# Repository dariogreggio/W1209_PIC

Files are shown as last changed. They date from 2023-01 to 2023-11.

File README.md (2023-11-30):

# W1209_PIC
a W1209 thermostat clone, made with a PIC, with added USB and OLED

NEW FEATURES: a complete game machine :)

and a fully configurable Timer
1) up to 999 seconds
2) selectable seconds or tenths of seconds (more customizable if needed)
3) start and stop by means of buttons, and external connector
4) stop/reset can be disabled
5) can start automatically at power-on
6) output can be either on or off (reversed mode) during timer operations
7) external input can work as either start or stop
8) complete real-time-clock (date and time) available
9) external output can be used as an analog input to change timing (customized)
12V (5..24V max) operating power supply

and a voltmeter!

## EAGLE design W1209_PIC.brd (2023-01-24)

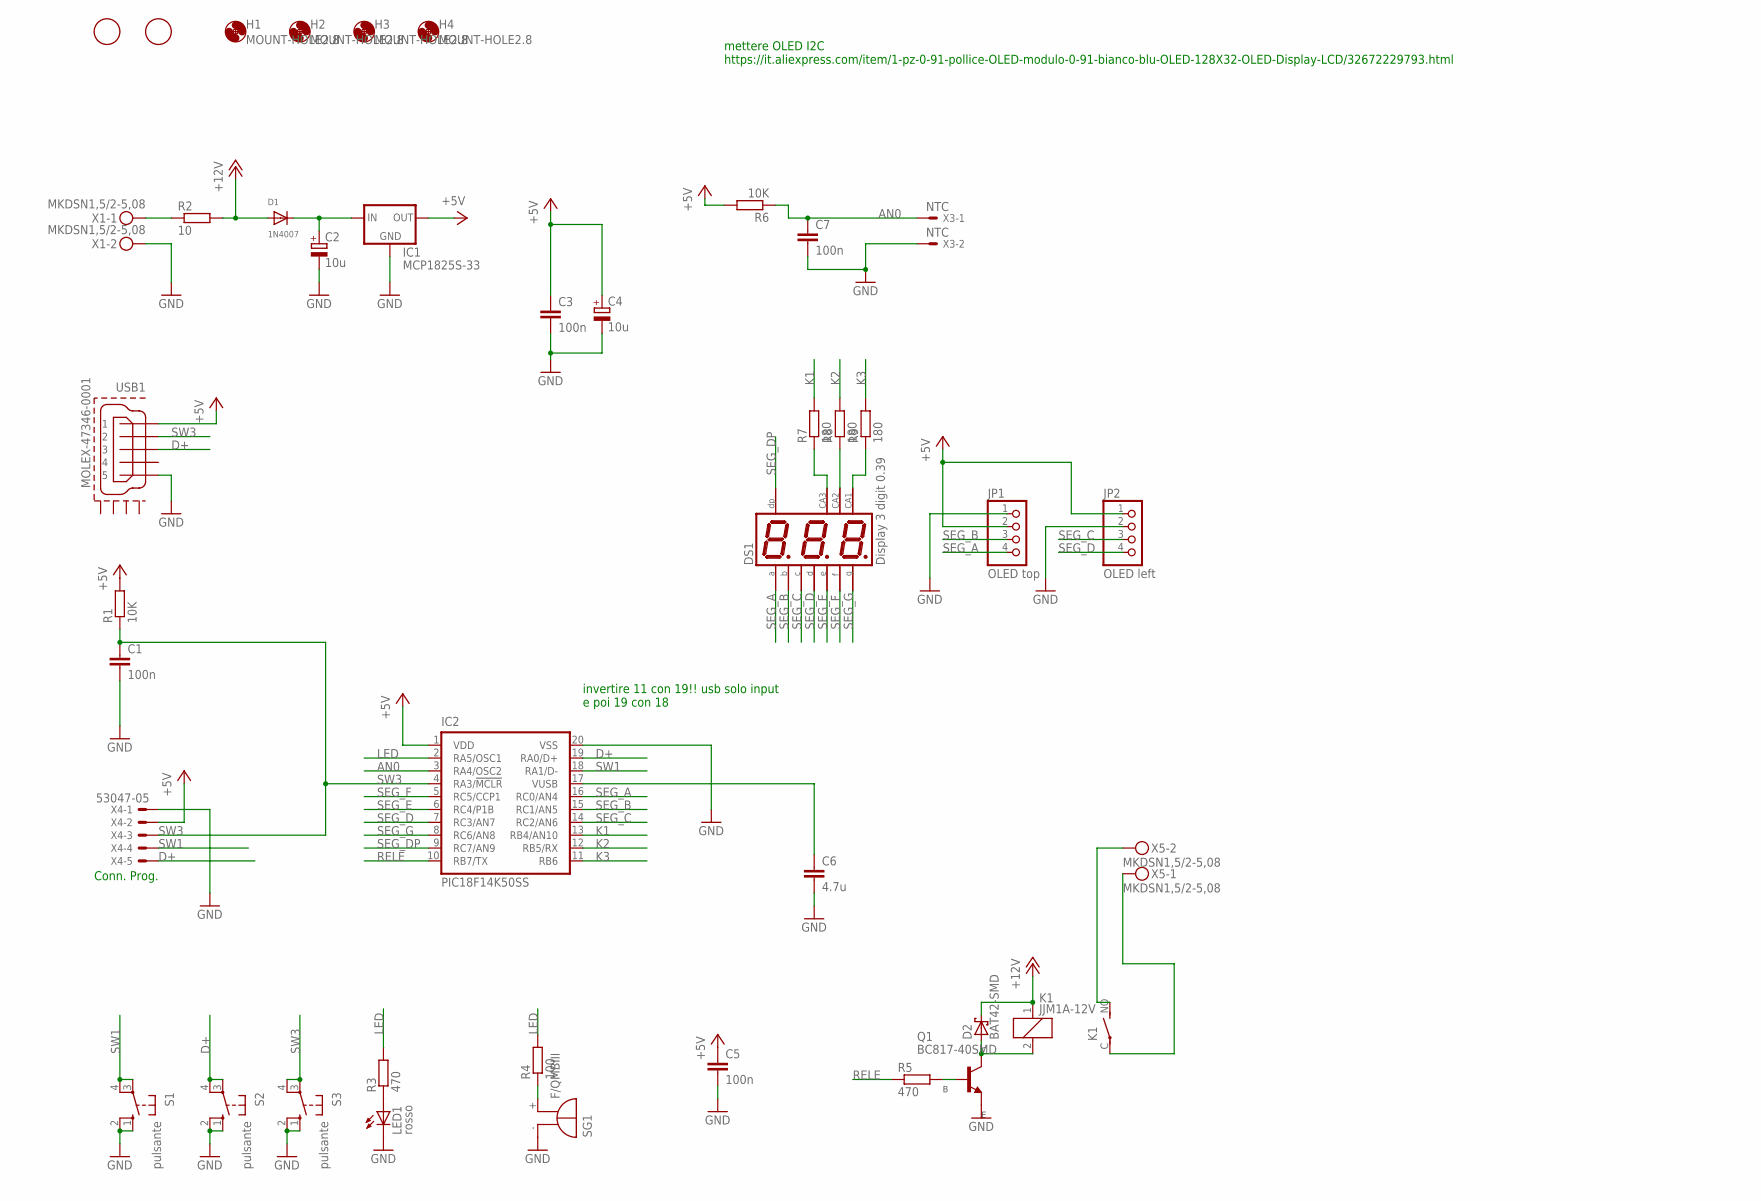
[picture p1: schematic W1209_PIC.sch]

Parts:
C1, C3, C5, C7: 100n; C0805
C2: 10u; SMC_C
C4: 10u; SMC_B
C6: 4.7u; C1206
D1: 1N4007; SMADIODE
D2: BAT42-SMD; DO214AC
DS1: Display 3 digit 0.39; KLT36XX
F1, F2: FIDUCIAL; FIDUCIAL_1MM
H1, H2, H3, H4: MOUNT-HOLE2.8; 2,8
IC1: MCP1825S-33; SOT223
IC2: PIC18F14K50SS; SS20
JP1: OLED top; 1X04
JP2: OLED left; 1X04
K1: JJM1A-12V; JJM1A
LED1: rosso; LD260
Q1: BC817-40SMD; SOT23-BEC
R1, R6: 10K; R0805
R2: 10; R2512
R3, R5: 470; R0805
R4: 100; R0805
R7, R8, R9: 180; R0805
S1, S2, S3: pulsante; B3F-10XX
SG1: F/QMBIII
USB1: MOLEX-47346-0001; MOLEX-47364-0001
X1, X5: MKDSN1,5/2-5,08
X3: NTC; KK-156-2
X4: 53047-05

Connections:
+5V: C3.1, C4.+, C5.1, IC1.3 (OUT), IC2.1 (VDD), JP1.2, JP2.1, R1.2, R6.2, USB1.1, X4.2
+12V: D1.A, D2.C, K1.1, R2.2
AN0: C7.1, IC2.3 (RA4/OSC2), R6.1, X3.1
D+: IC2.19 (RA0/D+), S2.3, S2.4 (P1), USB1.3, X4.5
GND: C1.2, C2.-, C3.2, C4.-, C5.2, C6.2, C7.2, IC1.2 (GND), IC1.4 (GND), IC2.20 (VSS), JP1.1, JP2.2, LED1.K (C), Q1.E, S1.1 (S), S1.2 (S1), S2.1 (S), S2.2 (S1), S3.1 (S), S3.2 (S1), SG1.- (+), USB1.5, X1.2, X3.2, X4.1
K1: IC2.13 (RB4/AN10), R7.2
K2: IC2.12 (RB5/RX), R8.2
K3: IC2.11 (RB6), R9.2
LED: IC2.2 (RA5/OSC1), R3.2, R4.2
unnamed: C2.+, D1.C, IC1.1 (IN)
unnamed: D2.A, K1.2, Q1.C
unnamed: K1.C, X5.1
unnamed: K1.NO (S), X5.2
unnamed: R4.1, SG1.+ (-)
unnamed: R2.1, X1.1
unnamed: DS1.P$12 (CA), R7.1
unnamed: DS1.P$8 (CA), R9.1
unnamed: DS1.P$9 (CA), R8.1
unnamed: Q1.B, R5.2
unnamed: LED1.A, R3.1
unnamed: C6.1, IC2.17 (VUSB)
RELE: IC2.10 (RB7/TX), R5.1
SEG_A: DS1.P$11 (A), IC2.16 (RC0/AN4), JP1.4
SEG_B: DS1.P$7 (B), IC2.15 (RC1/AN5), JP1.3
SEG_C: DS1.P$4 (C), IC2.14 (RC2/AN6), JP2.3
SEG_D: DS1.P$2 (D), IC2.7 (RC3/AN7), JP2.4
SEG_DP: DS1.P$3 (DP), IC2.9 (RC7/AN9)
SEG_E: DS1.P$1 (E), IC2.6 (RC4/P1B)
SEG_F: DS1.P$10 (F), IC2.5 (RC5/CCP1)
SEG_G: DS1.P$5 (G), IC2.8 (RC6/AN8)
SW1: IC2.18 (RA1/D-), S1.3, S1.4 (P1), X4.4
SW3: C1.1, IC2.4 (RA3/!MCLR!), R1.1, S3.3, S3.4 (P1), USB1.2, X4.3

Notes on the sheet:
Conn. Prog.
mettere OLED I2C https://it.aliexpress.com/item/1-pz-0-91-pollice-OLED-modulo-0-91-bianco-blu-OLED-128X32-OLED-Display-LCD/32672229793.html
invertire 11 con 19!! usb solo input e poi 19 con 18

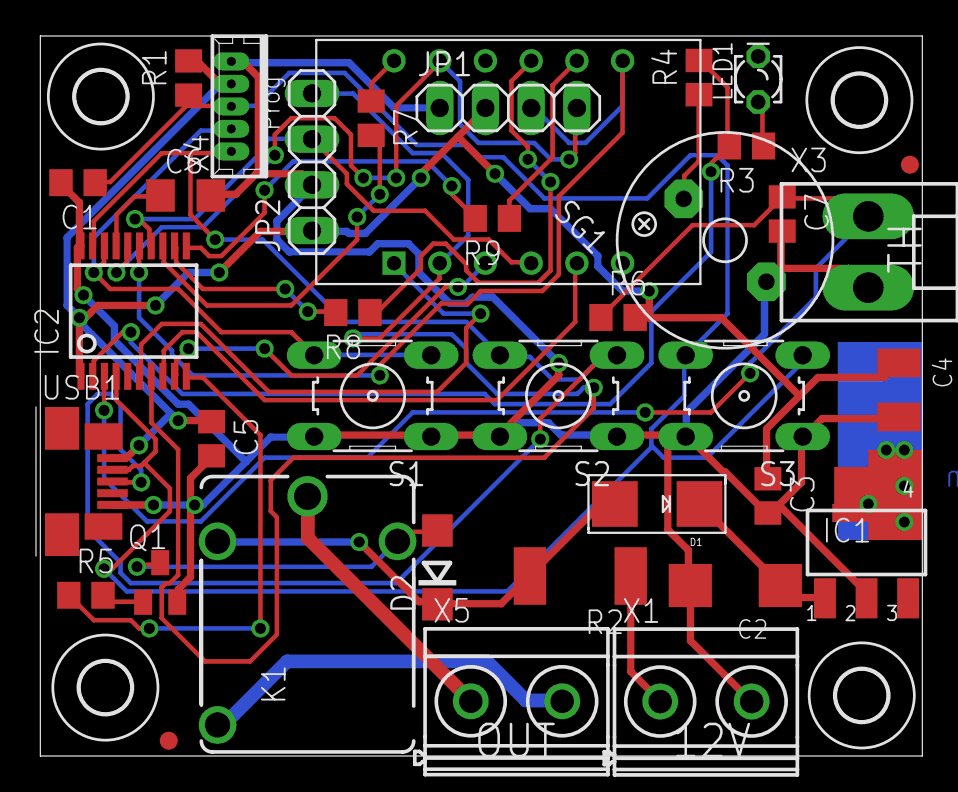
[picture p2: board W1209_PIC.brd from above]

Board: 2 copper layers, 49.0 x 40.0 mm, 41 parts (0 on the bottom side), 32 nets.

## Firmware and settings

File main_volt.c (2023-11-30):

/********************************************************************
 FileName:		main.c
 Dependencies:	See INCLUDES section
 Processor:		PIC16, PIC18, PIC24, and PIC32 USB Microcontrollers
 Hardware:		This demo is natively intended to be used on Microchip USB demo
 				boards supported by the MCHPFSUSB stack.  See release notes for
 				support matrix.  This demo can be modified for use on other hardware
 				platforms.
 Complier:  	Microchip C18 (for PIC18), C30 (for PIC24), C32 (for PIC32)
 Company:		Microchip Technology, Inc.

 Software License Agreement:

 The software supplied herewith by Microchip Technology Incorporated
 (the Company) for its PIC® Microcontroller is intended and
 supplied to you, the Company?s customer, for use solely and
 exclusively on Microchip PIC Microcontroller products. The
 software is owned by the Company and/or its supplier, and is
 protected under applicable copyright laws. All rights are reserved.
 Any use in violation of the foregoing restrictions may subject the
 user to criminal sanctions under applicable laws, as well as to
 civil liability for the breach of the terms and conditions of this
 license.


********************************************************************
 File Description:

 Change History:
  Rev   Description
  ----  -----------------------------------------
  2.6a  Added support for PIC24FJ256GB210

  2.7   No change

  2.8   Improvements to USBCBSendResume(), to make it easier to use.
  2.9   Added event transfer terminated handler code, for improved MSD
        error case handling.  Increased RAM reserved for the C software 
        stack on PIC18 devices.  The previous version did not allocate
        enough RAM for the worst case scenario, when USB_INTERRUPTS mode
        was used, causing potentially unexpected operation.

W1209 voltmetro
(basato su pcb W1209)
 GD 29/11/2023

********************************************************************/

/** INCLUDES *******************************************************/

#include <stdio.h>
#include <string.h>
#include <ctype.h>

#if defined(__18CXX)
#include <delays.h>
#include <reset.h>
#include <timers.h>
#include <portb.h>
#include <adc.h>
//#include <outcompare.h>
#else
//#include "Flash.h"
#include "HEFlash.h"
#endif

#include "w1209_volt.h"

//#include "swi2c.h"

#ifdef USA_USB
#include "USB.h"
#endif
#include "HardwareProfile.h"


#ifdef USA_USB
#include "usb_function_hid.h"
#endif


/** CONFIGURATION **************************************************/

#if defined(__18CXX)
// https://forum.microchip.com/s/topic/a5C3l000000MUIBEA4/t346503 per pin speciali

        #pragma config CPUDIV = NOCLKDIV
        #pragma config USBDIV = OFF
//        #pragma config FOSC   = HS  per USB SERVE quarzo! 6 o 24MHz...
//        #pragma config PLLEN  = ON
        #pragma config FOSC   = IRC		// HS  per USB SERVE quarzo! 6 o 24MHz...
        #pragma config PLLEN  = OFF		// vado a 8 MHz... v. sotto
        #pragma config FCMEN  = OFF
        #pragma config IESO   = ON
        #pragma config PWRTEN = ON
        #pragma config BOREN  = OFF
        #pragma config BORV   = 30
        #pragma config WDTEN  = OFF
        #pragma config WDTPS  = 32768
        #pragma config MCLRE  = OFF
        #pragma config HFOFST = OFF
        #pragma config STVREN = ON
        #pragma config LVP    = OFF
#ifdef __EXTENDED18__
        #pragma config XINST    = ON       // Extended Instruction Set
#else
        #pragma config XINST    = OFF
#endif
        #pragma config BBSIZ  = OFF
        #pragma config CP0    = OFF
        #pragma config CP1    = OFF
        #pragma config CPB    = OFF
        #pragma config WRT0   = OFF
        #pragma config WRT1   = OFF
        #pragma config WRTB   = OFF
        #pragma config WRTC   = OFF
        #pragma config EBTR0  = OFF
        #pragma config EBTR1  = OFF
        #pragma config EBTRB  = OFF       


#pragma romdata myidlocs=0x200000
const rom char data0=0x04u;
const rom char data1=0x04u;
const rom char data2=0x04u;
const rom char data3=0x07u;
const rom char data4=0x00u;
const rom char data5=0x00u;
const rom char data6=0x00u;
const rom char data7=0x00u;
#pragma romdata
#endif


#if defined(__XC8)
// PIC16F1459 Configuration Bit Settings
// 'C' source line config statements

// CONFIG1
#pragma config FOSC = INTOSC    // Oscillator Selection Bits (INTOSC oscillator: I/O function on CLKIN pin)
#pragma config WDTE = ON        // Watchdog Timer Enable (WDT enabled)
#pragma config PWRTE = ON      // Power-up Timer Enable (PWRT enabled)
#pragma config MCLRE = OFF       // MCLR Pin Function Select (MCLR/VPP pin function is I/O)
#pragma config CP = OFF         // Flash Program Memory Code Protection (Program memory code protection is disabled)
#pragma config BOREN = ON       // Brown-out Reset Enable (Brown-out Reset enabled)
#pragma config CLKOUTEN = OFF   // Clock Out Enable (CLKOUT function is disabled. I/O or oscillator function on the CLKOUT pin)
#pragma config IESO = ON        // Internal/External Switchover Mode (Internal/External Switchover Mode is enabled)
#pragma config FCMEN = ON       // Fail-Safe Clock Monitor Enable (Fail-Safe Clock Monitor is enabled)

// CONFIG2
#pragma config WRT = OFF        // Flash Memory Self-Write Protection (Write protection off)
#pragma config CPUDIV = CLKDIV6 // CPU System Clock Selection Bit (CPU system clock divided by 6)
#pragma config USBLSCLK = 48MHz // USB Low SPeed Clock Selection bit (System clock expects 48 MHz, FS/LS USB CLKENs divide-by is set to 8.)
#pragma config PLLMULT = 3x     // PLL Multipler Selection Bit (3x Output Frequency Selected)
#pragma config PLLEN = ENABLED  // PLL Enable Bit (3x or 4x PLL Enabled)
#pragma config STVREN = ON      // Stack Overflow/Underflow Reset Enable (Stack Overflow or Underflow will cause a Reset)
#pragma config BORV = LO        // Brown-out Reset Voltage Selection (Brown-out Reset Voltage (Vbor), low trip point selected.)
#pragma config LPBOR = OFF      // Low-Power Brown Out Reset (Low-Power BOR is disabled)
#pragma config LVP = OFF         // Low-Voltage Programming Enable (Low-voltage programming disabled (dice che altrimenti si perde MCLR I/O..)
// ma i pin usb/ICSP funziano solo in LVP!!

// #pragma config statements should precede project file includes.
// Use project enums instead of #define for ON and OFF.

#include <xc.h>

#endif


/** VARIABLES ******************************************************/
#if defined(__18CXX)
#pragma udata
#endif

#define CLOCK_TUNE_DEFAULT 960		//perde 1 ora su 12, 25/6/12, ecc
WORD clockTune=CLOCK_TUNE_DEFAULT;		//deve andare in Flash...

#ifdef __DEBUG
BYTE SW[3]={1,1,1};
#endif

enum EDITS {
	MENU_NOEDIT=0,
	MENU_VOLT,
	MENU_VOLTRANGE,
	MENU_SECONDI,
	MENU_MINUTI,
	MENU_ORA,
	MENU_GIORNO,
	MENU_MESE,
	MENU_ANNO,
	MENU_MAX
	};


static const rom char CopyrString[]= {'V','o','l','t','m','e','t','r','o',' ','W','1','2','0','9',' ',
#ifdef USA_USB
'c','o','n',' ','U','S','B',' ',
#endif
	'v',VERNUMH+'0','.',VERNUML/10+'0',(VERNUML % 10)+'0', ' ','3','0','/','1','1','/','2','3', 0 };

const rom BYTE table_7seg[]={ 0, 	//PGFEDCBA
													0b00111111,0b00000110,0b01011011,0b01001111,0b01100110,
										 			0b01101101,0b01111101,0b00000111,0b01111111,0b01101111,
													0b01000000,
//													0b00000001,0b00000010,0b00000100,0b00001000,0b00010000,	//indicatori...
//													0b00100000,0b01000000,0b10000000
//													0b01110100,0b01010100,0b01101101,0b01100111,0b00110111,	//indicatori...
//													0b01110111,0b01111000,0b10000000
													0b01110111,0b01111100,0b00111001,0b01011110,0b01111001,0b01110001,	//A..F
													0b00111101,0b01110110,0b00110000,0b00001110,0b01110110,0b00111000,	//G..L
													0b00110111,0b01010100,0b01011100,0b01110011,0b01100111,0b01010000,	//M..R (o piccola per distinguere)
													0b01101101,0b01111000,0b00111110,0b00011100,0b00011100,0b00110110,	//S..X
													0b01101110,0b01011011		//Y..Z
	};

#if defined(__18CXX)
#pragma udata

#if defined(__18F14K50) || defined(__18F13K50) || defined(__18LF14K50) || defined(__18LF13K50) 
    #pragma udata usbram2
#elif defined(__18F2455) || defined(__18F2550) || defined(__18F4455) || defined(__18F4550)\
    || defined(__18F2458) || defined(__18F2453) || defined(__18F4558) || defined(__18F4553)
    #pragma udata USB_VARIABLES=0x500
#elif defined(__18F4450) || defined(__18F2450)
    #pragma udata USB_VARIABLES=0x480
#else
    #pragma udata
#endif
#endif
#if defined(__XC8)
    #if defined(_18F14K50) || defined(_18F13K50) || defined(_18LF14K50) || defined(_18LF13K50)
        #define IN_DATA_BUFFER_ADDRESS 0x260
        #define OUT_DATA_BUFFER_ADDRESS (IN_DATA_BUFFER_ADDRESS + HID_INT_IN_EP_SIZE)
        #define IN_DATA_BUFFER_ADDRESS_TAG @IN_DATA_BUFFER_ADDRESS
        #define OUT_DATA_BUFFER_ADDRESS_TAG @OUT_DATA_BUFFER_ADDRESS
    #elif  defined(_18F2455)   || defined(_18F2550)   || defined(_18F4455)  || defined(_18F4550)\
        || defined(_18F2458)   || defined(_18F2453)   || defined(_18F4558)  || defined(_18F4553)\
        || defined(_18LF24K50) || defined(_18F24K50)  || defined(_18LF25K50)\
        || defined(_18F25K50)  || defined(_18LF45K50) || defined(_18F45K50)
        #define IN_DATA_BUFFER_ADDRESS 0x500
        #define OUT_DATA_BUFFER_ADDRESS (IN_DATA_BUFFER_ADDRESS + HID_INT_IN_EP_SIZE)
        #define IN_DATA_BUFFER_ADDRESS_TAG @IN_DATA_BUFFER_ADDRESS
        #define OUT_DATA_BUFFER_ADDRESS_TAG @OUT_DATA_BUFFER_ADDRESS
    #elif defined(_18F4450) || defined(_18F2450)
        #define IN_DATA_BUFFER_ADDRESS 0x480
        #define OUT_DATA_BUFFER_ADDRESS (IN_DATA_BUFFER_ADDRESS + HID_INT_IN_EP_SIZE)
        #define IN_DATA_BUFFER_ADDRESS_TAG @IN_DATA_BUFFER_ADDRESS
        #define OUT_DATA_BUFFER_ADDRESS_TAG @OUT_DATA_BUFFER_ADDRESS
    #elif defined(_16F1459000)  
#warning  se lo metto dà errore RAM! VERIFICARE
        #define IN_DATA_BUFFER_ADDRESS 0x2050
        #define OUT_DATA_BUFFER_ADDRESS (IN_DATA_BUFFER_ADDRESS + HID_INT_IN_EP_SIZE)
        #define IN_DATA_BUFFER_ADDRESS_TAG @IN_DATA_BUFFER_ADDRESS
        #define OUT_DATA_BUFFER_ADDRESS_TAG @OUT_DATA_BUFFER_ADDRESS
    #else
        #define IN_DATA_BUFFER_ADDRESS_TAG
        #define OUT_DATA_BUFFER_ADDRESS_TAG
    #endif
#else
    #define IN_DATA_BUFFER_ADDRESS_TAG
    #define OUT_DATA_BUFFER_ADDRESS_TAG
#endif

#if defined(__XC8)
volatile unsigned char hid_report_in[HID_INT_IN_EP_SIZE] IN_DATA_BUFFER_ADDRESS_TAG;
volatile unsigned char hid_report_out[HID_INT_OUT_EP_SIZE] OUT_DATA_BUFFER_ADDRESS_TAG;
#endif
#define ReceivedDataBuffer hid_report_out
#define ToSendDataBuffer hid_report_in
//unsigned char ReceivedDataBuffer[HID_INT_IN_EP_SIZE];
//unsigned char ToSendDataBuffer[HID_INT_OUT_EP_SIZE];

#if defined(__18CXX)
#pragma udata
#endif


#ifdef USA_USB
USB_HANDLE USBOutHandle = 0;
USB_HANDLE USBInHandle = 0;
#endif


BYTE USBOn=FALSE,MenuMode;
struct SAVED_PARAMETERS configParms;

#if defined(__18CXX)
#ifndef __EXTENDED18__
#pragma udata access ACCESSBANK
#else
#pragma udata gpr0
#define near
#endif
#endif
#if defined(__18CXX)
volatile near unsigned char Displays[3];			// 3 display 
#else
volatile unsigned char Displays[3];			// 3 display 
#endif

#if defined(__18CXX)
#pragma udata gpr0
#endif
volatile BYTE dim=FALSE;
BYTE Buzzer=0;
WORD Voltage=0;
static BYTE firstPassDisplay=20;
volatile WORD tick10=0;
volatile BYTE second_10=0;
#if defined(__XC8)
//volatile PIC24_RTCC_DATE currentDate;
//volatile PIC24_RTCC_TIME currentTime;
#else
//volatile PIC24_RTCC_DATE currentDate={0,0,0};
//volatile PIC24_RTCC_TIME currentTime={0,0,0};
#endif
const BYTE dayOfMonth[12]={31,28,31,30,31,30,31,31,30,31,30,31};
volatile DWORD milliseconds;


#define TickGet() (tick10)

/** PRIVATE PROTOTYPES *********************************************/
static void InitializeSystem(void);
int UserInit(void);
#ifdef USA_USB
void USBDeviceTasks(void);
void ProcessIO(void);
void sendEP1(void);
void USBCBSendResume(void);
#endif


/** DECLARATIONS ***************************************************/

void bumpClock(void) {
	BYTE i;

	while(milliseconds >= 1000) {
		milliseconds -= 1000;
		configParms.currentTime.sec++;
		if(configParms.currentTime.sec >= 60) {
			configParms.currentTime.sec=0;
			configParms.currentTime.min++;
			if(configParms.currentTime.min >= 60) {
				configParms.currentTime.min=0;
				configParms.currentTime.hour++;
				if(configParms.currentTime.hour >= 24) {
					configParms.currentTime.hour=0;
					configParms.currentDate.mday++;
					i=dayOfMonth[configParms.currentDate.mon-1];
					if((i==28) && !(configParms.currentDate.year % 4))
						i++;
					if(configParms.currentDate.mday > i) {		// (rimangono i secoli...)
						configParms.currentDate.mday=0;
						configParms.currentDate.mon++;
						if(configParms.currentDate.mon >= 12) {		// 
							configParms.currentDate.mon=1;
							configParms.currentDate.year++;
							}
						}
					}
				}
			} 
		} 
	}


/********************************************************************
 * Function:        void main(void)
 *
 * PreCondition:    None
 *
 * Input:           None
 *
 * Output:          None
 *
 * Side Effects:    None
 *
 * Overview:        Main program entry point.
 *
 * Note:            None
 *******************************************************************/
#if defined(__18CXX)
void main(void)
#else
int main(void)
#endif
{   
//  unsigned int i;

  InitializeSystem();

/*	TRISA=0;
	while(1) {
		LATA ^= 0xffff;
		ClrWdt();
		}
*/


	UserInit();

#ifdef USA_USB
  #if defined(USB_INTERRUPT)
//    USBDeviceAttach();
  #endif
#endif


  while(1) {

		ClrWdt();

#ifdef USA_USB
    #if defined(USB_POLLING)
// Check bus status and service USB interrupts.
#ifndef __DEBUG
  	USBDeviceTasks(); // Interrupt or polling method.  If using polling, must call
#endif
    				  // this function periodically.  This function will take care
    				  // of processing and responding to SETUP transactions 
    				  // (such as during the enumeration process when you first
    				  // plug in).  USB hosts require that USB devices should accept
    				  // and process SETUP packets in a timely fashion.  Therefore,
    				  // when using polling, this function should be called 
    				  // regularly (such as once every 1.8ms or faster** [see 
    				  // inline code comments in usb_device.c for explanation when
    				  // "or faster" applies])  In most cases, the USBDeviceTasks() 
    				  // function does not take very long to execute (ex: <100 
    				  // instruction cycles) before it returns.
    #endif
				  

  #if defined(USB_INTERRUPT)
    if(USB_BUS_SENSE && (USBGetDeviceState() == DETACHED_STATE)) { 
      USBDeviceAttach(); 
    	} 
    else    // ADDED BY ANGUEL 
    if(!USB_BUS_SENSE && (USBGetDeviceState() != DETACHED_STATE)) { 
      USBDeviceDetach(); 
//			USBDeviceState= DETACHED_STATE;
    	} 
  #endif
#endif


// Application-specific tasks.
// Application related code may be added here, or in the ProcessIO() function.
#ifdef USA_USB
    ProcessIO();        // 

    //if we are in the enumeration process then we don't want to start initializing
    // the FAT library.  It takes too 
    if((USBDeviceState < CONFIGURED_STATE) && (USBDeviceState > ATTACHED_STATE)) {
//      continue; no...
    	}
#endif

//mLED_1^=1;

	UserTasks();

  } //end while
    
  
	} //end main

/********************************************************************
 * Function:        static void InitializeSystem(void)
 *
 * PreCondition:    None
 *
 * Input:           None
 *
 * Output:          None
 *
 * Side Effects:    None
 *
 * Overview:        InitializeSystem is a centralize initialization
 *                  routine. All required USB initialization routines
 *                  are called from here.
 *
 *                  User application initialization routine should
 *                  also be called from here.                  
 *
 * Note:            None
 *******************************************************************/
static void InitializeSystem(void) {

	ClrWdt();

#if !defined(__XC8)
	StatusReset();

	OSCCONbits.IRCF0=0;		// 8MHz con l'interno!
	OSCCONbits.IRCF1=1;
	OSCCONbits.IRCF2=1;
	OSCTUNE = 0b00000000;			// provo a scendere verso 6MHz per USB :D ma fa il +-3.2% al max...
//(PLL va solo se 8MHz...)
#else
  OSCTUNE = 0;
  OSCCON = 0xFC;          //16MHz HFINTOSC with 3x PLL enabled (48MHz operation)
  ACTCON = 0x90;          //Enable active clock tuning with USB
#endif

	CM1CON0=0b00000000;
	CM2CON0=0b00000000;
#if defined(__XC8)
	ANSELA=0b00000000;
	ANSELC=0b00000000;
	ANSELAbits.ANSA4=1;
#else
	ANSEL=0b00000000;
	ANSELH=0b00000000;
	ANSELbits.ANS3=1;
#endif


	TRISA = 0b00011011;		// led; ev. AN0 o AN3 = RA4; pulsanti;
	TRISB = 0b00000000;		// catodi; 
	TRISC = 0b00000000;		// display; OLed-I2C; 
//	ODCA  = 0b0000000010000000;		// open collector

  //Set the push button input
  mInitAllSwitches();
  //Set up the LED as output
  mInitAllLEDs();

	LATA = 0b00000000;		// 
	LATB = 0b00000000;		// ; 
	LATC = 0b00000000;		// 

	WPUA=0b00001011;			// usb cmq no...
	WPUB=0b00000000;

// https://forum.microchip.com/s/topic/a5C3l000000MCLJEA4/t277505 porcodio RA0 RA1
#ifndef __XC8
	IOCA= 0b00000011;
#endif


#if defined(__XC8)
  APFCON=0;     // no remapping
#endif

  
#ifdef USA_USB
//	The USB specifications require that USB peripheral devices must never source
//	current onto the Vbus pin.  Additionally, USB peripherals should not source
//	current on D+ or D- when the host/hub is not actively powering the Vbus line.
//	When designing a self powered (as opposed to bus powered) USB peripheral
//	device, the firmware should make sure not to turn on the USB module and D+
//	or D- pull up resistor unless Vbus is actively powered.  Therefore, the
//	firmware needs some means to detect when Vbus is being powered by the host.
//	A 5V tolerant I/O pin can be connected to Vbus (through a resistor), and
// 	can be used to detect when Vbus is high (host actively powering), or low
//	(host is shut down or otherwise not supplying power).  The USB firmware
// 	can then periodically poll this I/O pin to know when it is okay to turn on
//	the USB module/D+/D- pull up resistor.  When designing a purely bus powered
//	peripheral device, it is not possible to source current on D+ or D- when the
//	host is not actively providing power on Vbus. Therefore, implementing this
//	bus sense feature is optional.  This firmware can be made to use this bus
//	sense feature by making sure "USE_USB_BUS_SENSE_IO" has been defined in the
//	HardwareProfile.h file.    
    #if defined(USE_USB_BUS_SENSE_IO)
    tris_usb_bus_sense = INPUT_PIN; // See HardwareProfile.h
    #endif
    
//	If the host PC sends a GetStatus (device) request, the firmware must respond
//	and let the host know if the USB peripheral device is currently bus powered
//	or self powered.  See chapter 9 in the official USB specifications for details
//	regarding this request.  If the peripheral device is capable of being both
//	self and bus powered, it should not return a hard coded value for this request.
//	Instead, firmware should check if it is currently self or bus powered, and
//	respond accordingly.  If the hardware has been configured like demonstrated
//	on the PICDEM FS USB Demo Board, an I/O pin can be polled to determine the
//	currently selected power source.  On the PICDEM FS USB Demo Board, "RA2" 
//	is used for	this purpose.  If using this feature, make sure "USE_SELF_POWER_SENSE_IO"
//	has been defined in HardwareProfile.h, and that an appropriate I/O pin has been mapped
//	to it in HardwareProfile.h.
    #if defined(USE_SELF_POWER_SENSE_IO)
    tris_self_power = INPUT_PIN;	// See HardwareProfile.h
    #endif
#endif


#if !defined(__XC8)
	RCONbits.IPEN=1;				// interrupt in Modalita' Avanzata!
#endif

#if defined(__XC8)
//	T0CON=0b00000011;								//
  OPTION_REG=0b00000100;    // pullup; prescaler 1:32
	T1CON=0b00110001;								// prescaler 1:8
	INTCONbits.T0IE = 1;
	PIE1bits.TMR1IE = 1;
	T3CON=fare 0b00110001;								// prescaler 1:4
#else
	OpenTimer0(TIMER_INT_ON & T0_8BIT & T0_SOURCE_INT & T0_PS_1_32);
										// (la frequenza di TMR0 e' 48/4MHz, divido per 32 )

	OpenTimer1(TIMER_INT_ON & T1_16BIT_RW & T1_SOURCE_INT & T1_PS_1_8 & T1_OSC1EN_OFF & T1_SYNC_EXT_OFF );
#endif

#if !defined(__XC8)
	INTCON2bits.TMR0IP=1;			//high pty Timer 0
	IPR1bits.TMR1IP=0;				//low pty Timer 1
#endif

	ClrWdt();
	

warm_reset:
	INTCONbits.GIE = 1;			// attiva interrupt globali / high pty
#if !defined(__XC8)
	INTCONbits.PEIE = 1;			// attiva low pty interrupt 
#endif

//	WriteTimer0(TMR0BASE);					// inizializzo TMR0
			//WRITETIMER0() dovrebbe essere la macro!

#if defined(__XC8)
  TMR1H=TMR1BASE/256;
	TMR1L=TMR1BASE & 255;
#else
	WriteTimer1(TMR1BASE);					// inizializzo TMR1
#endif


//  CM3CON=0;		// comparatori off (Rxpin) ?? boh


// buzzer 4KHz QUA in software essendo pin led/buzzer
#if !defined(__XC8)
#endif
//	T2CON=0b00000011;								// set prescaler T2
//	PR2=BEEP_STD_FREQ;


#if defined(__XC8)
	ADCON0=0b00001101;	//		; AN3 RA0 ; ON
	ADCON1=0b10100000;	//		; Right justify; FOsc/32; VRef +/-
	ADCON2=0b00000000;	//		; no autoconversion
#else
//	OpenADC(ADC_FOSC_32 & ADC_LEFT_JUST & ADC_12_TAD, ADC_CH3 & ADC_INT_OFF & ADC_VREFPLUS_VDD & ADC_VREFMINUS_VSS,
//	);
	// VERIFICA su questo PIC! 
	ADCON2=0b10001010;	//		; Right justify; 12 Tad, FOsc/32
	ADCON1=0b00000000;	//		; VRef +/-
	ADCON0=0b00001101;	//		; AN3 RA4 ; ON
#endif


#ifdef USA_USB
#ifndef __DEBUG
  USBDeviceInit();
#endif
#endif

	} //end InitializeSystem
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

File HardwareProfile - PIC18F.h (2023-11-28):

/********************************************************************
 FileName:      HardwareProfile.h
 Dependencies:  See INCLUDES section
 Processor:     PIC18, PIC24, or PIC32 USB Microcontrollers
 Hardware:      The code is natively intended to be used on the 
                  following hardware platforms: 
                    PICDEM™ FS USB Demo Board
                    PIC18F46J50 FS USB Plug-In Module
                    PIC18F87J50 FS USB Plug-In Module
                    Explorer 16 + PIC24 or PIC32 USB PIMs
                    PIC24F Starter Kit
                    Low Pin Count USB Development Kit
                  The firmware may be modified for use on other USB 
                    platforms by editing this file (HardwareProfile.h)
 Compiler:  	Microchip C18 (for PIC18), C30 (for PIC24), 
                  or C32 (for PIC32)
 Company:       Microchip Technology, Inc.

 Software License Agreement:

 The software supplied herewith by Microchip Technology Incorporated
 (the “Company”) for its PIC® Microcontroller is intended and
 supplied to you, the Company’s customer, for use solely and
 exclusively on Microchip PIC Microcontroller products. The
 software is owned by the Company and/or its supplier, and is
 protected under applicable copyright laws. All rights are reserved.
 Any use in violation of the foregoing restrictions may subject the
 user to criminal sanctions under applicable laws, as well as to
 civil liability for the breach of the terms and conditions of this
 license.

********************************************************************
 File Description:

 Change History:
  Rev   Date         Description
  1.0   11/19/2004   Initial release
  2.1   02/26/2007   Updated for simplicity and to use common coding style
  2.3   09/15/2008   Broke out each hardware platform into its own
                     "HardwareProfile - xxx.h" file
********************************************************************/

#ifndef HARDWARE_PROFILE_PIC18_H
#define HARDWARE_PROFILE_PIC18_H

//#define DEMO_BOARD USER_DEFINED_BOARD

#include "usb_config.h"

//#if defined(USA_USB)			servono cmq se compili la robba usb in progetto...

    //#define USE_SELF_POWER_SENSE_IO
    #define tris_self_power       // Input
    #define self_power          1

    //#define USE_USB_BUS_SENSE_IO
    #define tris_usb_bus_sense      // Input
    #define USB_BUS_SENSE       1 

   
    //Uncomment this to make the output HEX of this project 
    //   to be able to be bootloaded using the HID bootloader
//    #define PROGRAMMABLE_WITH_USB_HID_BOOTLOADER	

    //If the application is going to be used with the HID bootloader
    //  then this will provide a function for the application to 
    //  enter the bootloader from the application (optional)



    /** Board definition ***********************************************/
    //These definitions will tell the main() function which board is
    //  currently selected.  This will allow the application to add
    //  the correct configuration bits as wells use the correct
    //  initialization functions for the board.  These defitions are only
    //  required in the stack provided demos.  They are not required in
    //  final application design.

#if defined(USA_USB) // v. sopra
    #define CLOCK_FREQ 48000000L
    #define GetSystemClock() CLOCK_FREQ   
		#define GetPeripheralClock() (CLOCK_FREQ/4)
#else
    #define CLOCK_FREQ 8000000L
    #define GetSystemClock() CLOCK_FREQ   
		#define GetPeripheralClock() (CLOCK_FREQ/4)
#endif

    /** LED ************************************************************/

		#define mInitAllLEDs()      LATA &= 0b11011111; TRISA &= 0b11011111;
    
		// 
    #define mLED_1              LATAbits.LATA5
    #define mGetLED_1()         mLED_1
    #define mLED_1_On()         mLED_1 = 1;
    #define mLED_1_Off()        mLED_1 = 0;
    #define mLED_1_Toggle()     mLED_1 ^= 1;

    
    /** SWITCH *********************************************************/
    #define mInitSwitch1()      // fisso TRISAbits.TRISA3=1;
    #define mInitSwitch2()      // fisso TRISAbits.TRISA1=1;
    #define mInitSwitch3()      // fisso TRISAbits.TRISA0=1;
    #define mInitAllSwitches()  mInitSwitch1();mInitSwitch2();mInitSwitch3();
#ifndef __DEBUG
    #define sw1                 PORTAbits.RA1
    #define sw2                 PORTAbits.RA0
		#define sw3                 PORTAbits.RA3
#else	// simulatore non va per questi @#£$%
    #define sw1                 SW[0]
    #define sw2                 SW[1]
		#define sw3                 SW[2]
#endif
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

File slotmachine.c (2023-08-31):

/********************************************************************
 FileName:     main.c
 Dependencies: See INCLUDES section
 Processor:		PIC18, PIC24, and PIC32 USB Microcontrollers
 Hardware:		This demo is natively intended to be used on Microchip USB demo
 				boards supported by the MCHPFSUSB stack.  See release notes for
 				support matrix.  This demo can be modified for use on other hardware
 				platforms.
 Complier:  	Microchip C18 (for PIC18), C30 (for PIC24), C32 (for PIC32)
 Company:		Microchip Technology, Inc.

 Software License Agreement:

********************************************************************
 File Description:

 Change History:
  Rev   Description
  ----  -----------------------------------------
  1.0   5/2022 Initial release, basata su LX336 (n. 65/1979) di Nuova Elettronica
  1.1   8/2023 adattata a W1209PIC :) e con aggiunte giochi vari


Dedicato alla dolce guerra :) (il nasdaq muore, le atomiche arrivano...)

********************************************************************/

#ifndef MAIN_C
#define MAIN_C

/** INCLUDES *******************************************************/

#include <generictypedefs.h>
#include <delays.h>
#include <timers.h>
#include <reset.h>
#include <pwm.h>
#include <portb.h>
#include <stdio.h>
#include <stdlib.h>
#include "slotmachine.h"
#include "hardwareprofile - pic18F.h"

/** CONFIGURATION **************************************************/


// https://forum.microchip.com/s/topic/a5C3l000000MUIBEA4/t346503 per pin speciali

        #pragma config CPUDIV = NOCLKDIV
        #pragma config USBDIV = OFF
//        #pragma config FOSC   = HS  per USB SERVE quarzo! 6 o 24MHz...
//        #pragma config PLLEN  = ON
        #pragma config FOSC   = IRC		// HS  per USB SERVE quarzo! 6 o 24MHz...
        #pragma config PLLEN  = OFF		// vado a 8 MHz... v. sotto
        #pragma config FCMEN  = OFF
        #pragma config IESO   = ON
        #pragma config PWRTEN = ON
        #pragma config BOREN  = OFF
        #pragma config BORV   = 30
        #pragma config WDTEN  = OFF
        #pragma config WDTPS  = 32768
        #pragma config MCLRE  = OFF
        #pragma config HFOFST = OFF
        #pragma config STVREN = ON
        #pragma config LVP    = OFF
#ifdef __EXTENDED18__
        #pragma config XINST    = ON       // Extended Instruction Set
#else
        #pragma config XINST    = OFF
#endif
        #pragma config BBSIZ  = OFF
        #pragma config CP0    = OFF
        #pragma config CP1    = OFF
        #pragma config CPB    = OFF
        #pragma config WRT0   = OFF
        #pragma config WRT1   = OFF
        #pragma config WRTB   = OFF
        #pragma config WRTC   = OFF
        #pragma config EBTR0  = OFF
        #pragma config EBTR1  = OFF
        #pragma config EBTRB  = OFF       


#pragma romdata
static rom const char CopyrString[]= {'C','y','b','e','r','d','y','n','e',' ','(','A','D','P','M',')',' ','-',' ','G','i','o','c','h','i','n','i',' ','7','s','e','g',' ',
	VERNUMH+'0','.',VERNUML/10+'0',(VERNUML % 10)+'0', ' ','3','1','/','0','8','/','2','3', 0 };

const rom BYTE table_7seg[]={0, // .GFEDCBA
															0b00111111,0b00000110,0b01011011,0b01001111,0b01100110,
												 			0b01101101,0b01111101,0b00000111,0b01111111,0b01101111,
															0b01000000,			// il segno meno...

													0b01110111,0b01111100,0b00111001,0b01011110,0b01111001,0b01110001,	//A..F
													0b00111101,0b01110110,0b00110000,0b00001110,0b01110110,0b00111000,	//G..L
													0b00110111,0b01010100,0b01011100,0b01110011,0b01100111,0b01010000,	//M..R (o piccola per distinguere)
													0b01101101,0b01111000,0b00111110,0b00011100,0b10011100,0b00110110,	//S..X
													0b01101110,0b01011011,		//Y..Z
//slot
															0b01001001,			// no palle; 12+26
															0b01101011,			// palla alta
															0b01011101,			// palla bassa
															0b01111111,			// due palle
//dadi
															0b01000000,			// 1; 16+26
															0b00001001,			// 2
															0b01001001,			// 3
															0b00110110,			// 4
															0b01110110,			// 5
															0b00111111,			// 6
															};

#pragma romdata myidlocs=0x200000
const rom char data0=0x04u;
const rom char data1=0x04u;
const rom char data2=0x04u;
const rom char data3=0x07u;
const rom char data4=0x00u;
const rom char data5=0x00u;
const rom char data6=0x00u;
const rom char data7=0x00u;
#pragma romdata

#pragma udata

#define BASE_FIRST 6
BYTE first=BASE_FIRST;

BYTE gameMode=0;
enum GIOCHI {
	GIOCO_SLOT=0,
	GIOCO_DADI,
	GIOCO_TOMBOLA,
	GIOCO_CASCADE,
	GIOCO_AUTO,
	GIOCO_RAZZO,
	GIOCO_SETTEMEZZO
	};
#define MAX_GIOCHI (GIOCO_SETTEMEZZO+1)
enum GIOCHI tipoGioco=GIOCO_SLOT;		//0=Slot, 1=Dadi, 2=tombola, 3=cascade, 4=auto, 5=atterraggio, 6=sette e mezzo
BYTE durataGioco,durataGioco2;
WORD Punti,totPunti;
BYTE posPlayer=1;
WORD mazzoDiCarte[4];		// 1bit per carta estratta, 10 opp. 13 x 4
BYTE numeriLotto[12];		// 90bit 



volatile BYTE tmr_cnt,second_1,second_100;
volatile BYTE Timer10;
BYTE dividerBeep;
BYTE dividerUI;


BYTE Displays[3][2];		// 3 display (display 3digit);

unsigned char dMode;


/** PRIVATE PROTOTYPES *********************************************/
static void InitializeSystem(void);
void ProcessIO(void);
void UserInit(void);
void YourHighPriorityISRCode();
void YourLowPriorityISRCode();


/** VECTOR REMAPPING ***********************************************/
	
	#pragma code HIGH_INTERRUPT_VECTOR = 0x08
	void High_ISR(void)
	{
  _asm 
	  goto YourHighPriorityISRCode 
	_endasm
	}
	#pragma code LOW_INTERRUPT_VECTOR = 0x18
	void Low_ISR(void)
	{
  _asm 
		goto YourLowPriorityISRCode
	_endasm
	}
	

#pragma code
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
